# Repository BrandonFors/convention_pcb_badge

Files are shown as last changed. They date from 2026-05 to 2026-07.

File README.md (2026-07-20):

# Convention Badge Project

## The Idea

To create a custom and interactive badge for conventions. The badge would have at least a display and a lipo power supply and some cool designs on the pcb. It would also probably have buttons for interactivity and other fun things.

## Design

ESP32C3 microcontroller. PCB designed in KiCad. Programming done with espressif

### V1

This design features a basic form factor supporting the XIAO esp32c3 devboard along with a 2.9 inch display module. The design was never actually manufactured.

### V2

The V2 board was designed to serve as both a badge and a dev board. It hosts the esp32c3, has support for USB power and flashing, has a battery managment circuit, and various peripherals. The display circuitry still lies on a breakout board which is attached through header pins. It is designed to resemble a satelite.

This design experience was particularly new/challenging because it was the first PCB design I made where I had to consider how parts and integrated circuits interact rather than wiring pin headers together. I also had to consider manufacturing requirements, part availability, and cost.

After manufacturing this board through JLCPCB, I was able to flash the ESP32C3 over USBC and get my display, buttons, and leds working. However, there were a few mistakes within the battery managment circuit that made LiPo power unusable for this version. I was able to fix one to get battery charging working, but a misconfigured mosfet connection made powering the uC with the battery impossible without some reworking which I don't have the tools for. 

Code at this stage is pretty scrappy as the main focus was on PCB design and just getting a prototype working.

Overall, I consider this version great progress and a great step towards improving my PCB design skills. Even though the main complexity of the battery managment circuitry doesn't work, I know what to fix in my next revision. This was my first project where programming wasn't really the main focus and I feel that I have a solid understanding of what to expect the design process to look like in my next KiCad project.

### V3 

Not Started.

This version will ideally look more like a sattelite or whatever form factor represents my interests. It also may switch to a digital display to enable more interactivity than an e-ink offers. 

Things that I had to rework/need to be fixed from V2:
- N-Mosfet for power source switching must align with datasheet
- Bulk capacitor added to display's power and GND. 
- S1 on FS8205A must be connected to ground. 
- Make lanyard hole a little smaller.
- Research general rules on where to put bulk/decoupling capacitors in a design and what type of capacitors are needed in various scenarios. 

## KiCad

All relevant kicad files can be found in `convention_badge_kicad`. We'll probably start by designing a basic board that would just serve as a platform for the esp32-c3 xiao and an e-paper breakoutboard with pin headers. After that, we can scale up complexity and embed the uC on the pcb badge and choose whether or not to design the badge with an FCC connection. 

One reference we are using is Notre Dame's build-a-board workshop pcb design which features a working esp32-c3 breakout board design.

Build-A-Board Credits: https://engineering.nd.edu/news/electrical-engineering-students-create-circuit-boards-in-inaugural-build-a-board-workshop/

# Design Notes

Everything below here is scattered notes from my dev process.

## Display options

### ESP32C3
Datasheet (contains schematics): https://documentation.espressif.com/esp32-c3-wroom-02_datasheet_en.pdf

- could go with xiao module as a backup
- could break out all available gpios to exposed vias to double as a breakout board for future use

### 2.13 inch e-Paper Display Module

 https://www.buydisplay.com/black-2-13-inch-e-paper-122x250-display-module-for-arduino-raspberry-pi

Datasheet: https://www.buydisplay.com/download/manual/ER-EPD0213-2-5076_Datasheet.pdf

UC8251 Controller: https://www.buydisplay.com/download/ic/UC8251.pdf

- is a breakout board and would be good for development on a breadboard. 
- has mounting holes that would be easy to use for the badge
- tutorial exists online for developing an entire display driver for this specific board.

The raw pannel: https://www.buydisplay.com/graphic-2-13-inch-122x250-electronic-paper-display-manufacturers

### 2.9 inch e-Paper Display Module

* probably the best considering size and scalability

https://www.buydisplay.com/black-2-9-inch-e-paper-display-module-for-arduino-raspberry-pi#

Datasheet: https://www.buydisplay.com/download/manual/ER-EPD029-2-5073_Datasheet.pdf

SSD1680 Controller: https://www.buydisplay.com/download/ic/SSD1680.pdf

- development board that is slightly larger and probably better for display purposes
- option for a breakout board and raw board if we decide to integrate pannel regulation into badge

The raw pannel: https://www.buydisplay.com/serial-2-9-inch-e-paper-screen-128x296-for-electronic-shelf-label-lcd

### 2.6 inch e-Paper Display Pannel

https://www.buydisplay.com/2-6-inch-e-ink-152x296-e-paper-display-panel-red-white-black-spi

Datasheet: https://www.buydisplay.com/download/manual/ER-EPD026A1-1_Datasheet.pdf

SSD1675A Controller: https://www.buydisplay.com/download/ic/SSD1675A.pdf

FCC Cable: https://www.buydisplay.com/download/connector/ER-CON24HT-1.pdf

- doesn't have breakout board 
- slightly larger
- requires 24 pin fcc ribbon cable and a connector

## Manufacturing

Most likely JLCPCB

Will likely have to pay for at least partial assembly. 

## Price Estimate

Claude session resulted in price estimate of ~$32 per board including assembly and shipping on an order of 5.

To minimize price, we can design a one sided board (the back) and hand solder buttons and attach the scren on the front. I don't think that prevents solder mask designs on the front. 

## Design Notes

### PCB_BadgeV1

This board will utilize the XIAO ESP32 C3 and an 2.9 inch e-Paper Display Module for functionality. Both will be soldered to the badge using header pins. A 3.7V lipo battery will be soldered to the underside of the xiao module as I don't have a way to solder the pads directly to the badge board. The board will also have some buttons on remaining usable gpio pins. 

This board is largely complete and contains support for a 2.9 inch epaper breakout and and esp32 c3 xiao soldered to the board using male header pins. One pin is wired to a voltage divider for battery power readings. The board also has support for 3 standard 6mm buttons which use internal pull up resistors on the esp32-c3. Footprints are mostly for through hole breadboard components purely because I am not space constrained and wanted to design the board for components that I already had on hand to avoid shipping/assembly costs.

The odds are that this board is never manufactured just because the next one will feature more peripherals as it won't be constrained by the pinout of the xiao. V2 will support the esp32-c3 directly on the pcb, based largely on the Build-A-Board pcb mentioned above.

Note: This board does not have decoupling capacitors between the e paper display and the 3.3V xiao supply.

#### Notable Resources

XIAO Getting Started: https://wiki.seeedstudio.com/XIAO_ESP32C3_Getting_Started/

Display Datasheet: Datasheet: https://www.buydisplay.com/download/manual/ER-EPD029-2-5073_Datasheet.pdf

### PCB_BadgeV2

This board will be 4 layers with support for the esp32-c3 directly on the pcb. Whether or not the board supports the e-paper display directly with no breakout is TBD. I might opt for a hybrid board that supports both the breakout board and the raw screen with solder bridges to enable/disable either set of connections. 

Section 13 of the SSD1680 Datasheet has a diagram of exactly what the 24 pin connector should be wired to.

10k PU with a 1uF capacitor on the EN line creates a RC time constant of 10ms, allowing EN to stay low on to 3.3V stabalizes so the chip boots properly.

I need some way to handle the battery managment of this design. I think I might need a battery charging IC.

Need to make sure that parts are in stock in jlcpcb

https://jlcpcb.com/parts

Going to create a charging/bms circuit using:
- TP4056
- DW10A
- FS8205A

Then I can use TLV75733P for voltage regulation and hook everything to the output 3.3V from there.

Added breakout pins for debugging purposes

Main section is 54 tall and 90 wide -> top and bottom pannels can be 19 tall w/ 3mm gaps between board and pannels

Hex design is 17.5mm tall and 88.1 mm wide

### Code Development

Notable E-Paper Sections:
- 9: Operation Flow 
- 8: Command Description
- 12.1: Timing table and diagram

Using EastRising's example code and the SD1680 documentation, I've got a working program that prints out an example image onto the screen. The display is electronically configured to be used vertically, but horizontal use is easily fixed with some clever frame buffer software. I'm just going to make it cycle through preconfigured bitmaps with the buttons to control the cycle.

Bitmap Img Converter: https://javl.github.io/image2cpp/

LUT Experiment Notes:
Refresh by default is pretty slow at 1.5 sec
- May be able to cut down with custom lut -> tradeoff is quality bc OTP lut does a full cycle on all pixels to fully clear them
Custom lut provided by east rising results in 0.9 sec refresh but leaves a faded img of the previous frame

In the future I can diff two frame buffers to find the changed pixels/sections and then use the xram and yram start/end points to selectively update the screen to avoid some of the anoying refresh.

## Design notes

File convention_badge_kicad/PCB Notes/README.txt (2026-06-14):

So you wanna make a pcb huh? Well you've come to the (probably wrong but) right place ;)

Here's my initial notes after looking at it for like 5 minutes

Your traces are all the same width, which isn't necessarily bad, but I'm worried about the 3.7V trace. Typically power lines have wider traces because they need to be able to supply the required current. Wider trace = more current capacity. It would be worth looking into  the nominal current draw of whatever you are supplying power to, and then using KiCad's trace width calculator in the project menu (very useful things underneath 'calculator tools') to calculate the minimum width of trace you need

The JST you are using for the battery is in the middle of the board. Fair play if that's what you want, but it'll probably be pretty annoying trying to connect to it. Typically all peripheral connectors are placed as close as possible to the edge of the board and facing out so it is a lot easier to access them (except perhaps for pin headers, but even then they tend to be on the outskirts of the board so they don't interfere with trace layout. In general, the layout for your power system is a but overly complex, and with a few small adjustments of component placement, the layout will be simpler and much more user friendly.

I'm unsure what the purpose of the solder jumper to GND for the battery is (I'm too lazy to check the datasheet of what you are messing with). If the purpose is to add an additional resistor to ground to make a voltage divider, I would suggest just via to GND right at the battery, via to GND close to the GND pad of the resistor and solder jumper from the other pad of the resistor to the voltage divider connection. That saves you from the long trace from the solder jumper to the battery, and in general its standard practice to place GND as close as possible to the pad to reduce the current return path (I don't really understand the physics but everything I see says to reduce the length of the return path as much as possible) Since you are working with low frequency I assume, it probably isn't an issue, but better safe then sorry.

You may be able to mess around with the placement and orientation of the Xiao thingie and your pin header connector to reduce via use. It probably isn't a big deal, but I at least try not to use vias whenever possible. But, if it's unavoidable its not a super big deal for your application

It shouldn't be a huge deal, but try to keep the power lines as far away as possible from the I2C lines. Power lines create larger magnetic fields (more current = more magnetic field intensity) and that can potentially corrupt your data as it is transmitted. Since it's only 3.7V and your lines are really short it shouldn't be a major major issue, but I would look into it to see how big of a problem it will be and just give it some space at least

Finally, your traces a just a bit messy. There's no reason not to use straight lines where applicable (For example, the two resistors can very easily be shifted so that there isn't a little hitch in the trace). Also, you have a weird little hanging trace on the connection to the 3rd button that can be cleaned up

Overall there'd definitely some things to touch up, but overall not too shabby! My biggest advice is to just mess around with component placement so that it 1. Makes sense for the user 2. Doesn't interfere with trace paths (especially for through hole components) *This doesn't apply too much to this board, but is good advice in general* 3. Allows for the simplest trace pathway

You have plenty of space on the board to play around with so don't be scared to try different setups!

LMK if you need any more help, I'm happy to give my thoughts whenever you need :)

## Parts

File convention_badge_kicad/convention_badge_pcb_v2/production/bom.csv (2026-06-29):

Designator | Footprint | Quantity | Value | LCSC Part #
C1 | 0603 | 1 | 1uF | C15849
C10, C3, C4 | C_CASE-A-3216-18(mm) | 3 | 10uF | C7171
C11, C2, C5, C9 | 0603 | 4 | 0.1uF | C14663
C6, C8 | 0603 | 2 | 2.2uF | C23630
C7 | C_CASE-B-3528-21(mm) | 1 | 100uF | C122271
D1 | D_0603 | 1 | YEL_LED | C2290
D2, D7 | D_0603 | 2 | RED_LED | C2286
D3 | D_DO-214AC(SMA) | 1 | SS14 | C2480
J1 | USB_C_Receptacle_GCT_USB4105-xx-A_16P_TopMnt_Horizontal | 1 | USBC | C2765186
J3 | JST_PH_S2B-PH-K_1x02_P2.00mm_Horizontal | 1 | 3.7V Battery | C173752
Q1 | SOT-23 | 1 | AO3401A | C20917
R1, R2 | R_0603 | 2 | 5.1k | C23186
R10, R3, R4 | 0805 | 3 | 10k | C17414
R11, R12, R13, R5, R6, R9 | R_0603 | 6 | 1k | C21190
R7 | R_0603 | 1 | 2.2k | C4190
R8 | R_0603 | 1 | 100 | C22775
SW1, SW2, SW6 | SW-SMD_4P-L5.1-W5.1-P3.70-LS6.5-TL-2 | 3 | SW4X2 | C318884
U1 | ESP32-C3-WROOM-02 | 1 | ESP32-C3-WROOM-02 | C2944070
U2 | SOT-23-6 | 1 | FS8205A | C908265
U3 | ESOP-8_L4.9-W3.9-P1.27-LS6.0-BL-EP | 1 | TP4056 | C16581
U4 | SOT-23-6 | 1 | DW01A | C351410
U5 | SOT-23-5 | 1 | TLV75733PDBV | C485517

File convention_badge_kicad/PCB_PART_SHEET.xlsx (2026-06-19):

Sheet: V1Parts
Part Number | Description | Manufacturer | Package | Designator | Count | Unit Price (USD) | Total Price | URL
113991054 | XIAO ESP32 C3 | seeed studio | Breakout | U1 | 1 | $4.99 | $4.99 | https://www.seeedstudio.com/Seeed-XIAO-ESP32C3-p-5431.html
ER-EPD029-2B-5073 | 2.9" E-Paper Display Breakout | East Rising | Breakout | J1 | 1 | $10.55 | $10.55 | https://www.buydisplay.com/black-2-9-inch-e-paper-display-module-for-arduino-raspberry-pi
2275319 | 3.7V Lipo Batt | Jameco | Battery | N/A | 1 | $6.54 | $6.54 | https://www.jameco.com/z/LJ503035-Jameco-ReliaPro-Lithium-Ion-Polymer-Battery-3-7V-500mAh-Rechargeable_2275319.html
 | 6mm standard push button |  | Through Hole | SW1-3 | 3 | $0.00 | $0.00
2314127 | Switch | Jameco | Through Hole | SW4 | 1 | $0.85 | $0.85 | https://www.jameco.com/z/EG218-Jameco-ValuePro-Slide-Switch-SPDT-ON-ON-500mA-50VDC-3-Pin-Breadboard-Friendly_2314127.html
 |  |  |  |  |  |  | $0.00
 |  |  |  |  |  |  | $0.00
 |  |  |  |  |  |  | $0.00
 |  |  |  |  |  |  | $0.00
 |  |  |  |  |  |  | $0.00
 |  |  |  |  |  |  | $0.00
 |  |  |  |  |  |  | $0.00
 |  |  |  |  |  |  | $0.00
 |  |  |  |  |  |  | $0.00
 |  |  |  |  |  |  | $0.00
 |  |  |  |  |  |  | $0.00
 |  |  |  |  |  |  | $0.00
 |  |  |  |  |  | Total Cost: | $22.93

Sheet: V2Parts
Part Number (JLCPCB) | Description | Manufacturer | Package | Designator | Count | Unit Price (USD) | Total Price | URL
 | Esp32C3 | espressif | Surface Mount |  | 1 |  | 0

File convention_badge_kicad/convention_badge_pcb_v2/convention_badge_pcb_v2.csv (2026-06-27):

Reference | Qty | Value | DNP | Footprint | LCSC
C1 | 1 | 1uF |  | Capacitor_SMD:C_0603_1608Metric | C15849
C2,C5,C9,C11 | 4 | 0.1uF |  | Capacitor_SMD:C_0603_1608Metric | C1590
C3,C4,C10 | 3 | 10uF |  | PCM_JLCPCB:C_CASE-A-3216-18(mm) | C7171
C6,C8 | 2 | 2.2uF |  | Capacitor_SMD:C_0603_1608Metric | C1607
C7 | 1 | 100uF |  | PCM_JLCPCB:C_CASE-B-3528-21(mm) | C122271
D1 | 1 | YEL_LED |  | PCM_JLCPCB:D_0603 | C2287
D2,D7 | 2 | RED_LED |  | PCM_JLCPCB:D_0603 | C2286
D3 | 1 | SS14 |  | PCM_JLCPCB:D_DO-214AC(SMA) | C2480
D4,D5 | 2 | LED | DNP | LED_THT:LED_D5.0mm
DISP1 | 1 | EPaper Breakout | DNP | 2_Displays:2.9_e_paper_ER-EPD029-2-5073
J1 | 1 | USBC |  | Connector_USB:USB_C_Receptacle_GCT_USB4105-xx-A_16P_TopMnt_Horizontal | C2765186
J2 | 1 | Conn_01x03_Pin | DNP | Connector_PinHeader_2.54mm:PinHeader_1x03_P2.54mm_Vertical
J3 | 1 | 3.7V Battery | DNP | Connector_JST:JST_PH_S2B-PH-K_1x02_P2.00mm_Horizontal | C173752
J4,J5 | 2 | Conn_01x07_Pin | DNP | Connector_PinHeader_2.54mm:PinHeader_1x07_P2.54mm_Vertical
Q1 | 1 | AO3401A |  | Package_TO_SOT_SMD:SOT-23 | C20917
R1,R2 | 2 | 5.1k |  | PCM_JLCPCB:R_0603 | C23186
R3,R4,R10 | 3 | 10k |  | Resistor_SMD:R_0805_2012Metric | C17414
R5,R6,R9,R11,R12,R13 | 6 | 1k |  | PCM_JLCPCB:R_0603 | C21190
R7 | 1 | 2.2k |  | PCM_JLCPCB:R_0603 | C4190
R8 | 1 | 100 |  | PCM_JLCPCB:R_0603 | C22775
SW1,SW2,SW6 | 3 | SW4X2 |  | PCM_JLCPCB:SW-SMD_4P-L5.1-W5.1-P3.70-LS6.5-TL-2 | C318884
SW3,SW4,SW5 | 3 | SW_Push | DNP | Button_Switch_THT:SW_PUSH_6mm
U1 | 1 | ESP32-C3-WROOM-02 |  | RF_Module:ESP32-C3-WROOM-02 | C2944070
U2 | 1 | FS8205A |  | Package_TO_SOT_SMD:SOT-23-6 | C908265
U3 | 1 | TP4056 |  | PCM_JLCPCB:ESOP-8_L4.9-W3.9-P1.27-LS6.0-BL-EP | C16581
U4 | 1 | DW01A |  | Package_TO_SOT_SMD:SOT-23-6 | C351410
U5 | 1 | TLV75733PDBV |  | Package_TO_SOT_SMD:SOT-23-5 | C485517

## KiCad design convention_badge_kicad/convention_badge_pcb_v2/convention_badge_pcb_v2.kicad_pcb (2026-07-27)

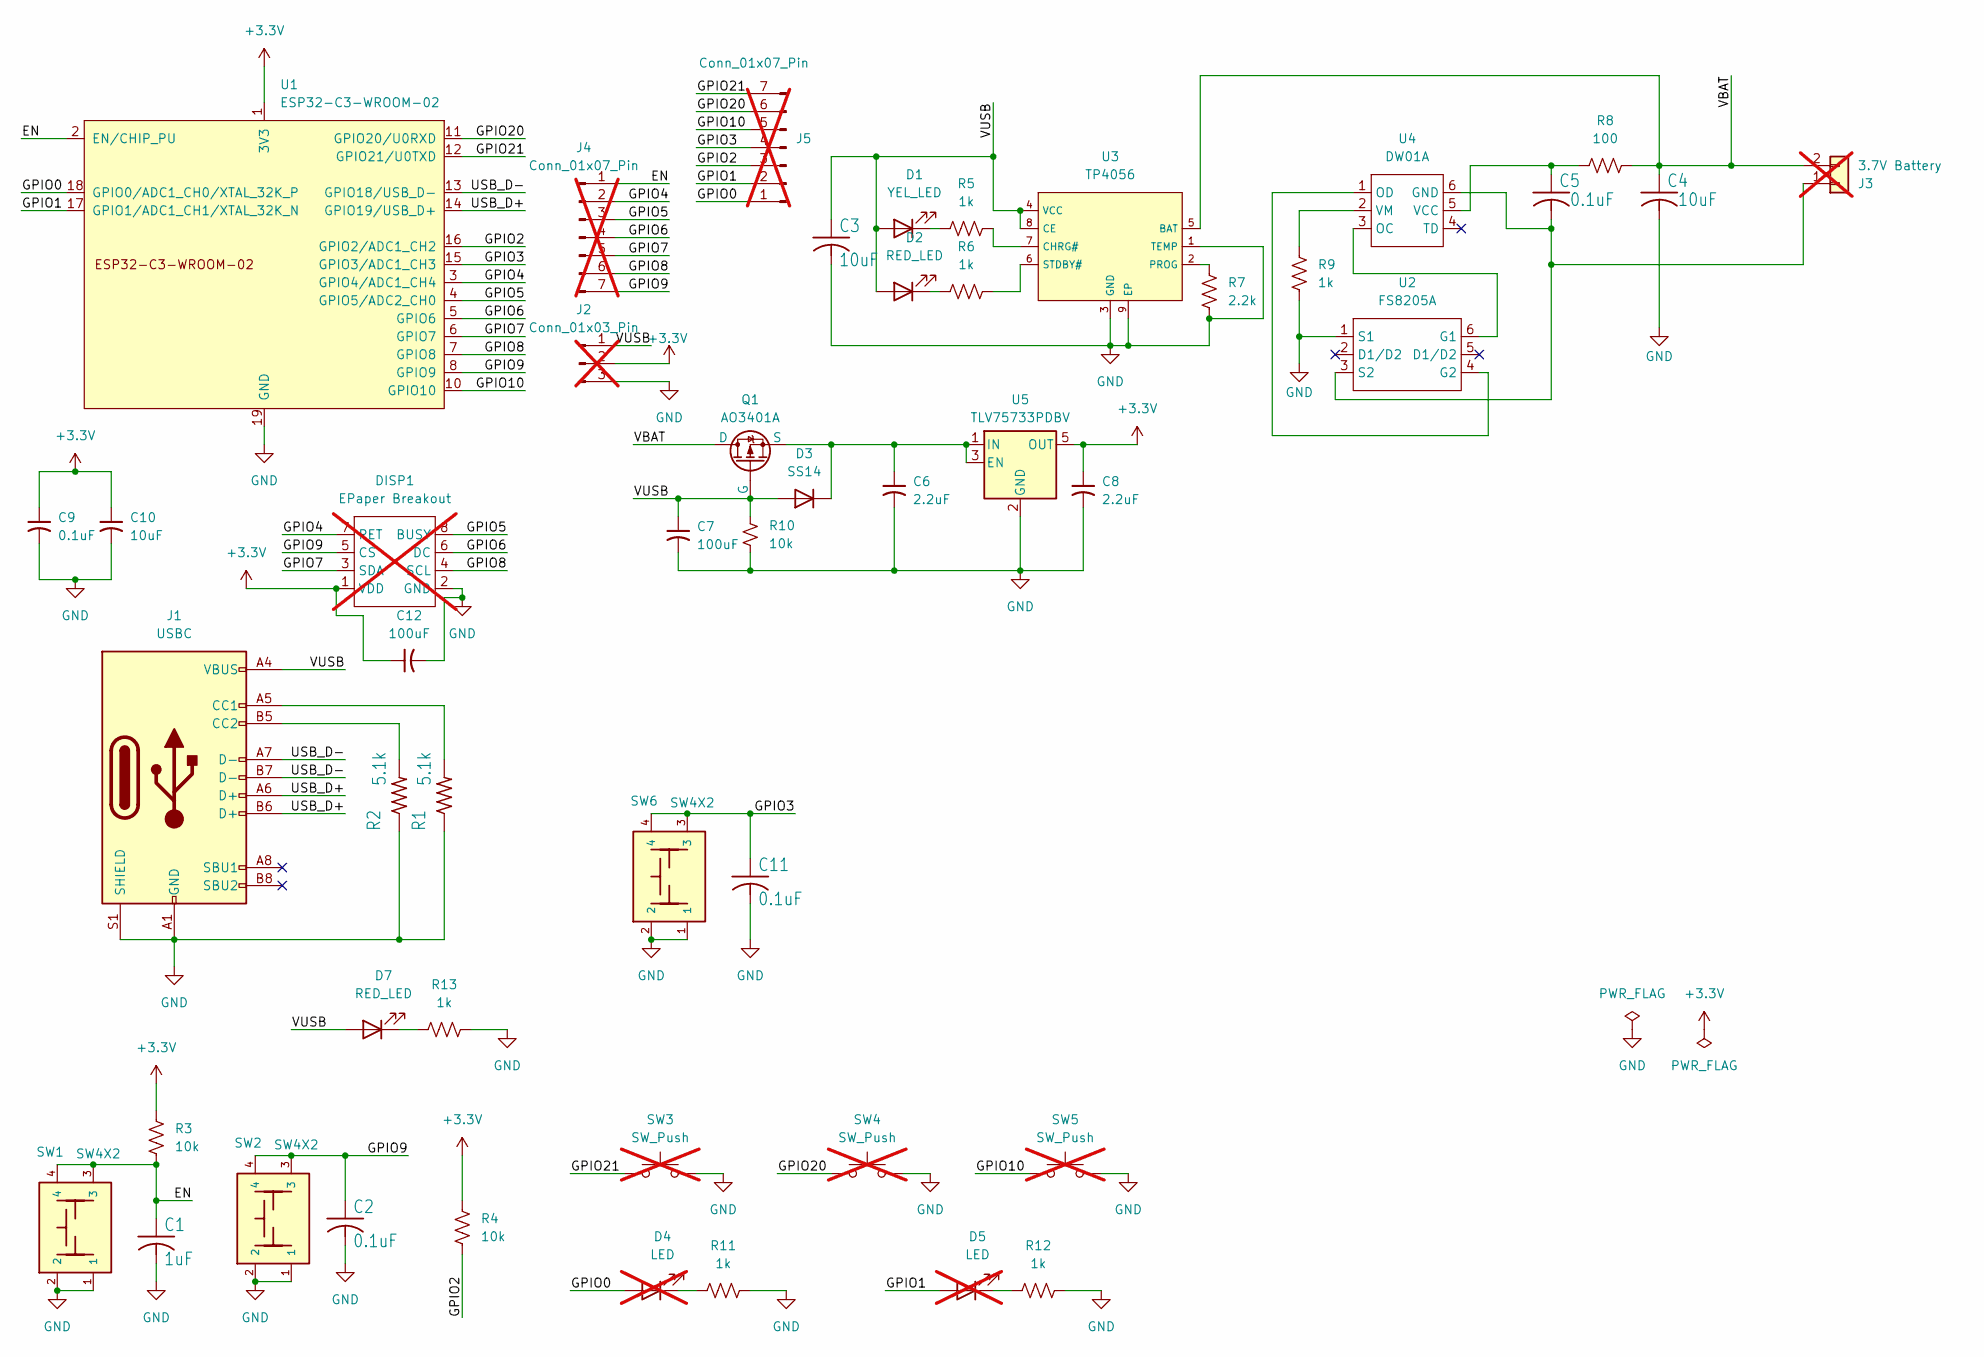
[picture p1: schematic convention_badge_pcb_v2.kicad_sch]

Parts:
C1: 1uF; C_0603_1608Metric; LCSC C15849
C2, C5, C9, C11: 0.1uF; C_0603_1608Metric; LCSC C14663
C3, C4, C10: 10uF; C_CASE-A-3216-18(mm); LCSC C7171
C6, C8: 2.2uF; C_0603_1608Metric; LCSC C23630
C7, C12: 100uF; C_CASE-B-3528-21(mm); LCSC C122271
D1: YEL_LED; D_0603; LCSC C2290
D2, D7: RED_LED; D_0603; LCSC C2286
D3: SS14; D_DO-214AC(SMA); LCSC C2480
D4, D5: LED; LED_D5.0mm; not fitted
DISP1: EPaper Breakout; 2.9_e_paper_ER-EPD029-2-5073; not fitted
J1: USBC; USB_C_Receptacle_GCT_USB4105-xx-A_16P_TopMnt_Horizontal; LCSC C2765186
J2: Conn_01x03_Pin; PinHeader_1x03_P2.54mm_Vertical; LCSC C2337; not fitted
J3: 3.7V Battery; JST_PH_S2B-PH-K_1x02_P2.00mm_Horizontal; LCSC C173752; not fitted
J4, J5: Conn_01x07_Pin; PinHeader_1x07_P2.54mm_Vertical; not fitted
Q1: AO3401A; SOT-23; LCSC C20917
R1, R2: 5.1k; R_0603; LCSC C23186
R3, R4, R10: 10k; R_0805_2012Metric; LCSC C17414
R5, R6, R9, R11, R12, R13: 1k; R_0603; LCSC C21190
R7: 2.2k; R_0603; LCSC C4190
R8: 100; R_0603; LCSC C22775
SW1, SW2, SW6: SW4X2; SW-SMD_4P-L5.1-W5.1-P3.70-LS6.5-TL-2; LCSC C318884
SW3, SW4, SW5: SW_Push; SW_PUSH_6mm; not fitted
U1: ESP32-C3-WROOM-02; LCSC C2944070
U2: FS8205A; SOT-23-6; LCSC C908265
U3: TP4056; ESOP-8_L4.9-W3.9-P1.27-LS6.0-BL-EP; Part TP4056-42-ESOP8; LCSC C16581
U4: DW01A; SOT-23-6; LCSC C351410
U5: TLV75733PDBV; SOT-23-5; LCSC C485517

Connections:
+3.3V: C8.1, C9.1, C10.1, C12.1, DISP1.1 (VDD), J2.2, R3.1, R4.1, U1.1 (3V3), U5.5 (OUT)
/EN: C1.1, J4.1, R3.2, SW1.3, SW1.4, U1.2 (EN/CHIP_PU)
/GPIO0: D4.2 (A), J5.1, U1.18 (GPIO0/ADC1_CH0/XTAL_32K_P)
/GPIO1: D5.2 (A), J5.2, U1.17 (GPIO1/ADC1_CH1/XTAL_32K_N)
/GPIO2: J5.3, R4.2, U1.16 (GPIO2/ADC1_CH2)
/GPIO3: C11.1, J5.4, SW6.3, SW6.4, U1.15 (GPIO3/ADC1_CH3)
/GPIO4: DISP1.7 (RET), J4.2, U1.3 (GPIO4/ADC1_CH4)
/GPIO5: DISP1.8 (BUSY), J4.3, U1.4 (GPIO5/ADC2_CH0)
/GPIO6: DISP1.6 (DC), J4.4, U1.5 (GPIO6)
/GPIO7: DISP1.3 (SDA), J4.5, U1.6 (GPIO7)
/GPIO8: DISP1.4 (SCL), J4.6, U1.7 (GPIO8)
/GPIO9: C2.1, DISP1.5 (CS), J4.7, SW2.3, SW2.4, U1.8 (GPIO9)
/GPIO10: J5.5, SW5.1, U1.10 (GPIO10)
/GPIO20: J5.6, SW4.1, U1.11 (GPIO20/U0RXD)
/GPIO21: J5.7, SW3.1, U1.12 (GPIO21/U0TXD)
/USB_D+: J1.A6 (D+), J1.B6 (D+), U1.14 (GPIO19/USB_D+)
/USB_D-: J1.A7 (D-), J1.B7 (D-), U1.13 (GPIO18/USB_D-)
/VBAT: C4.1, J3.2, Q1.3 (D), R8.2, U3.5 (BAT)
/VUSB: C3.1, C7.1, D1.2 (A), D2.2 (A), D3.2 (A), D7.2 (A), J1.A4 (VBUS), J1.A9 (VBUS), J1.B4 (VBUS), J1.B9 (VBUS), J2.1, Q1.1 (G), R10.1, U3.4 (VCC), U3.8 (CE)
GND: C1.2, C2.2, C3.2, C4.2, C6.2, C7.2, C8.2, C9.2, C10.2, C11.2, C12.2, DISP1.2 (GND), J1.A1 (GND), J1.A12 (GND), J1.B1 (GND), J1.B12 (GND), J1.S1 (SHIELD), J2.3, R1.1, R2.1, R7.1, R9.1, R10.2, R11.2, R12.2, R13.2, SW1.1, SW1.2, SW2.1, SW2.2, SW3.2, SW4.2, SW5.2, SW6.1, SW6.2, U1.9 (GND), U1.19 (GND), U2.1 (S1), U3.1 (TEMP), U3.3 (GND), U3.9 (EP), U5.2 (GND)
unnamed: D1.1 (K), R5.1
unnamed: D2.1 (K), R6.1
unnamed: C6.1, D3.1 (K), Q1.2 (S), U5.1 (IN), U5.3 (EN)
unnamed: D4.1 (K), R11.1
unnamed: D5.1 (K), R12.1
unnamed: D7.1 (K), R13.1
unnamed: J1.A5 (CC1), R1.2
unnamed: J1.B5 (CC2), R2.2
unnamed: C5.2, J3.1, U2.3 (S2), U4.6 (GND)
unnamed: U2.6 (G1), U4.3 (OC)
unnamed: U2.4 (G2), U4.1 (OD)
unnamed: R5.2, U3.7 (CHRG#)
unnamed: R7.2, U3.2 (PROG)
unnamed: R6.2, U3.6 (STDBY#)
unnamed: C5.1, R8.1, U4.5 (VCC)
unnamed: R9.2, U4.2 (VM)

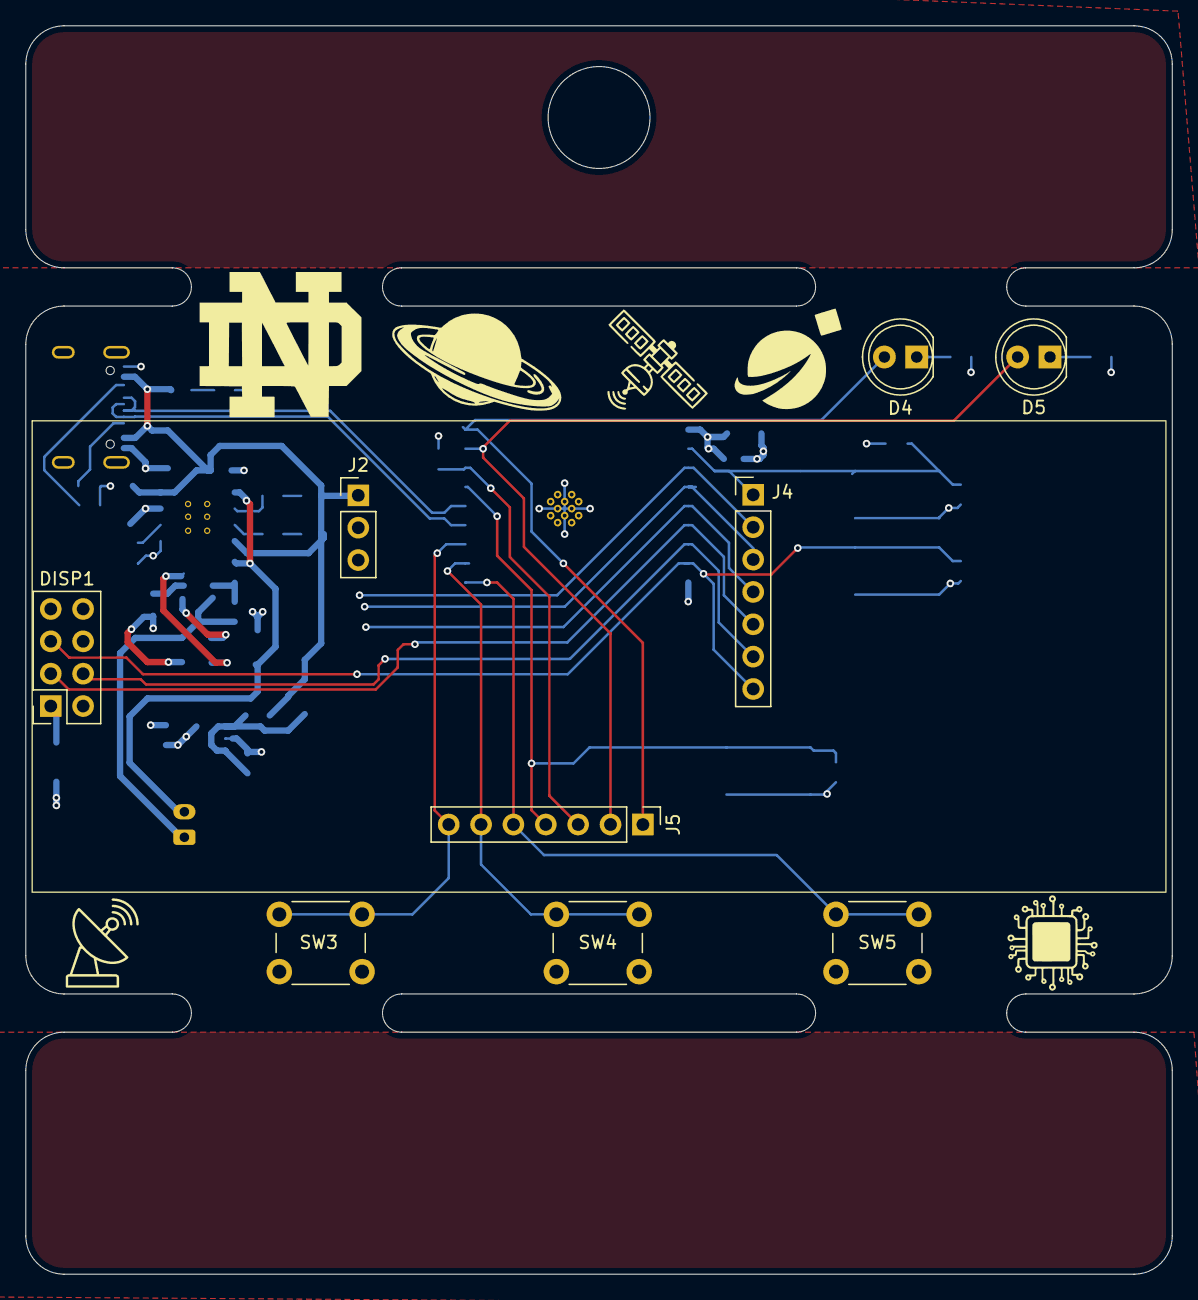
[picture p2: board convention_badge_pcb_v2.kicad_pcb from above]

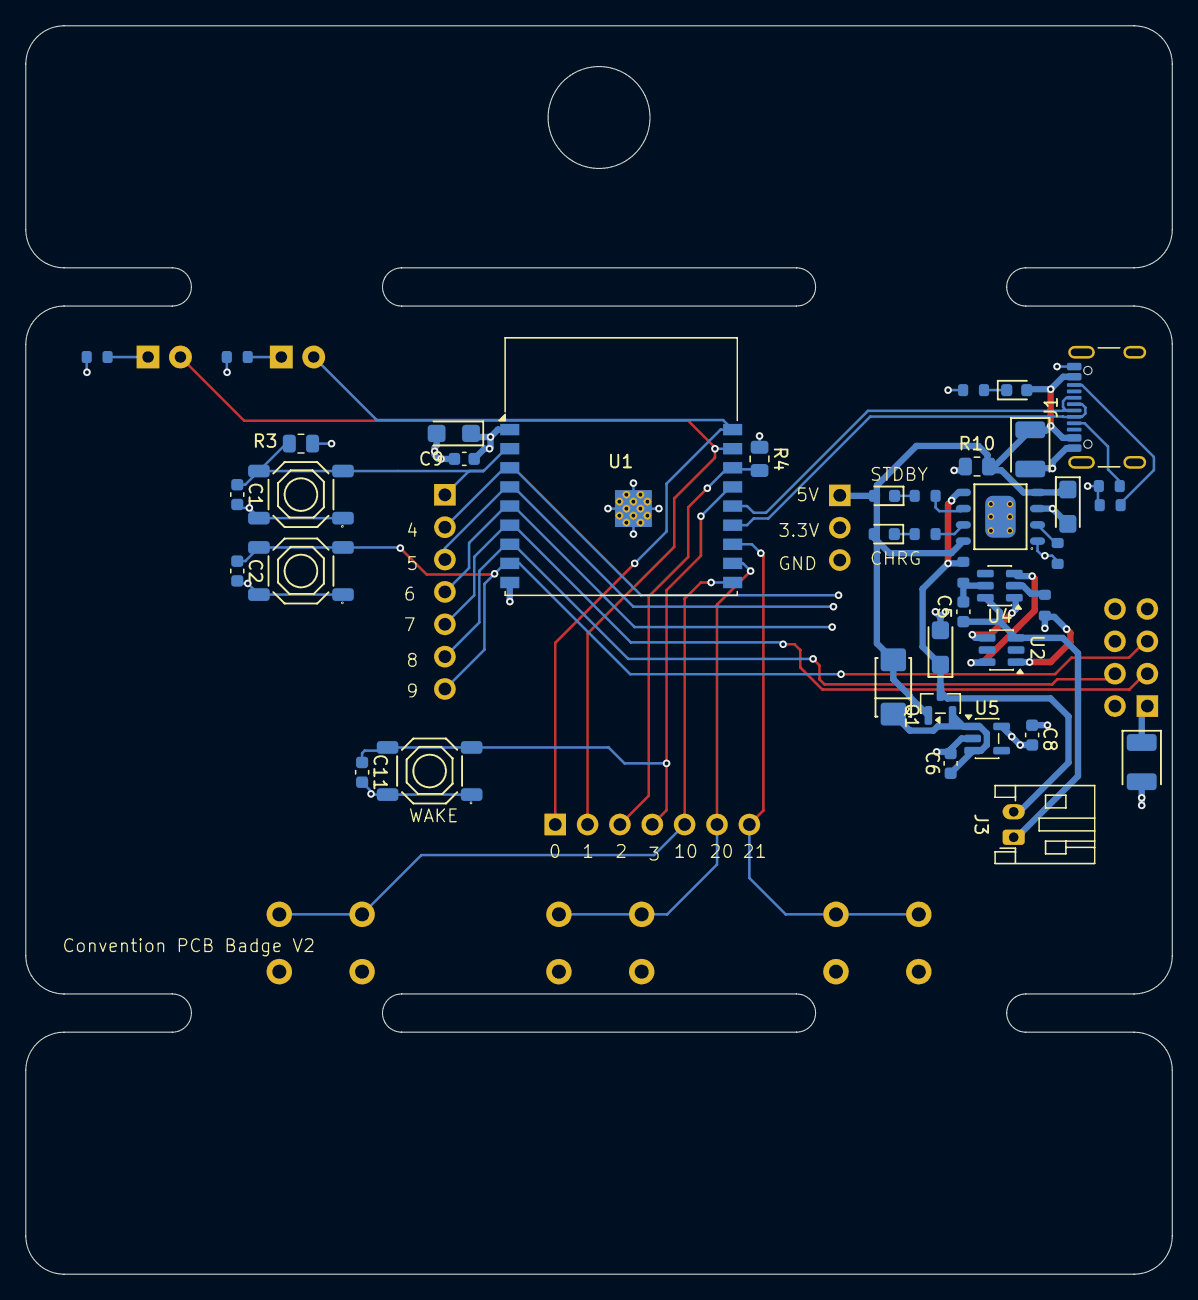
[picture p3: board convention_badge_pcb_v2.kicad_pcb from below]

Board: 4 copper layers, 90.0 x 98.0 mm, 49 parts (40 on the bottom side), 36 nets.

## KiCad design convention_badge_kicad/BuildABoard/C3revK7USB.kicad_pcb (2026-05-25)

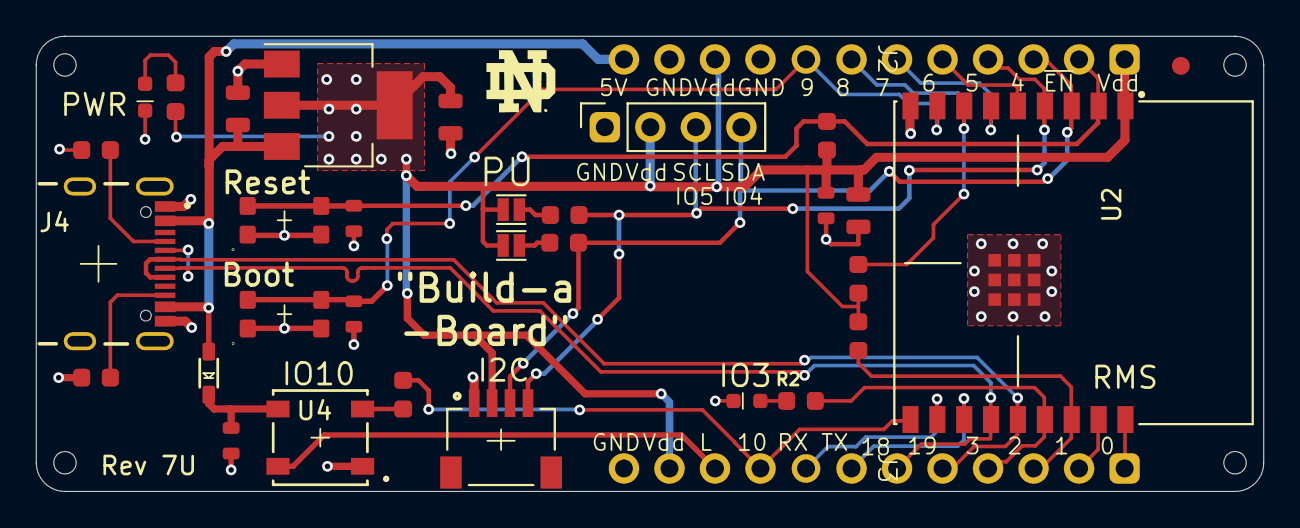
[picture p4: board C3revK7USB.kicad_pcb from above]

Board: 2 copper layers, 68.5 x 25.4 mm, 38 parts (0 on the bottom side), 28 nets.

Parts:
C1, C5: 10uf; STA_RMCF0805_STP
C2: 22uf; STA_RMCF0805_STP
C3, C6: .1uf; C0603
C4, C7: 1uf; C0603
D1: 1N4148; SOD323
FID1: Fiducial; Fiducial_1mm_Mask2mm
H1, H2, H3, H4: MountingHole; MountingHole_Small
J1: I2C; JST04_1MM_RA
J2, J3: Conn_01x12_Pin; Pin12rms
J4: USBC; GCT4105
JP1, JP3: DNP; Jumper_NO_Small
JP2: OLED; 1x4 Socket
LED1: Green; LED_0603
LED2: Blue; LED_0603
Logo1: LOGO; blocknd5x5
R1, R2: 1k; R0603
R3, R4, R5: 10k; R0603
R6, R7: 4.7k; R0603
R14: 470; R0603
R16, R17: 5.1k; R0603
SW1, SW2: SW4X2; PB4X2
U1: AZ1117; SOT223
U2: ESP32-C3; ESP32-C3-WROOM
U4: IN-5X5-LED; LED5x5mm

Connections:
/CC1: J4.A5 (CC1), R17.2
/CC2: J4.B5 (CC2), R16.2
/D+: J3.5, J4.A6 (DP), J4.B6 (DP), U2.14 (IO19)
/D-: J3.6, J4.A7 (DN), J4.B7 (DN), U2.13 (IO18)
/IO0: J3.1, U2.18 (IO0)
/IO1: J3.2, U2.17 (IO1)
/IO2: J3.3, R3.1, U2.16 (IO2)
/IO3: J3.4, R2.2, U2.15 (IO3)
/IO4/SDA: J1.3 (SDA), J2.3, JP2.4 (SDA), R6.1, U2.3 (IO4)
/IO5/SCL: J1.4 (SCL), J2.4, JP2.3 (SCL), R7.1, U2.4 (IO5)
/IO6: J2.5, U2.5 (IO6)
/IO7: J2.6, U2.6 (IO7)
/IO8: J2.7, R4.1, U2.7 (IO8)
/IO9: C3.1, J2.8, SW2.2, SW2.3, U2.8 (IO9)
/IO10: J3.9, R14.1, U2.10 (IO10)
/LED_O: J3.10, U4.2 (DOUT)
/VUSB: C1.1, D1.2, J2.12, J4.A4_B9 (VUSB), J4.B4_A9 (VUSB), U1.3 (INPUT)
/W-RX: J3.8, U2.11 (RXD)
/W-TX: J3.7, U2.12 (TXD)
/~EN: C4.1, J2.2, R5.1, SW1.2, SW1.3, U2.2 (EN)
GND: C1.2, C2.2, C3.2, C4.2, C5.2, C6.2, C7.2, J1.1 (GND), J2.9, J2.11, J3.12, J4.A1_B12 (GND), J4.B1_A12 (GND), J4.S1 (SHELL_GND), J4.S2 (SHELL_GND), J4.S3 (SHELL_GND), J4.S4 (SHELL_GND), JP2.1 (GND), LED1.1 (C), LED2.1 (C), R16.1, R17.1, SW1.1, SW1.4, SW2.1, SW2.4, U1.1 (GND), U2.9 (GND), U2.19 (GND), U2.20 (GND), U2.21 (GND), U2.22 (GND), U2.23 (GND), U2.24 (GND), U2.25 (GND), U2.26 (GND), U2.27 (GND), U4.1 (GND)
unnamed: JP1.1 (A), R6.2
unnamed: JP3.1 (A), R7.2
unnamed: LED1.2 (A), R1.1
unnamed: LED2.2 (A), R2.1
unnamed: C7.1, D1.1, U4.4 (5VDC)
unnamed: R14.2, U4.3 (DIN)
VDD: C2.1, C5.1, C6.1, J1.2 (VCC), J2.1, J2.10, J3.11, JP1.2 (B), JP2.2 (VDD), JP3.2 (B), R1.2, R3.2, R4.2, R5.2, U1.2 (OUTPUT), U2.1 (3V3)

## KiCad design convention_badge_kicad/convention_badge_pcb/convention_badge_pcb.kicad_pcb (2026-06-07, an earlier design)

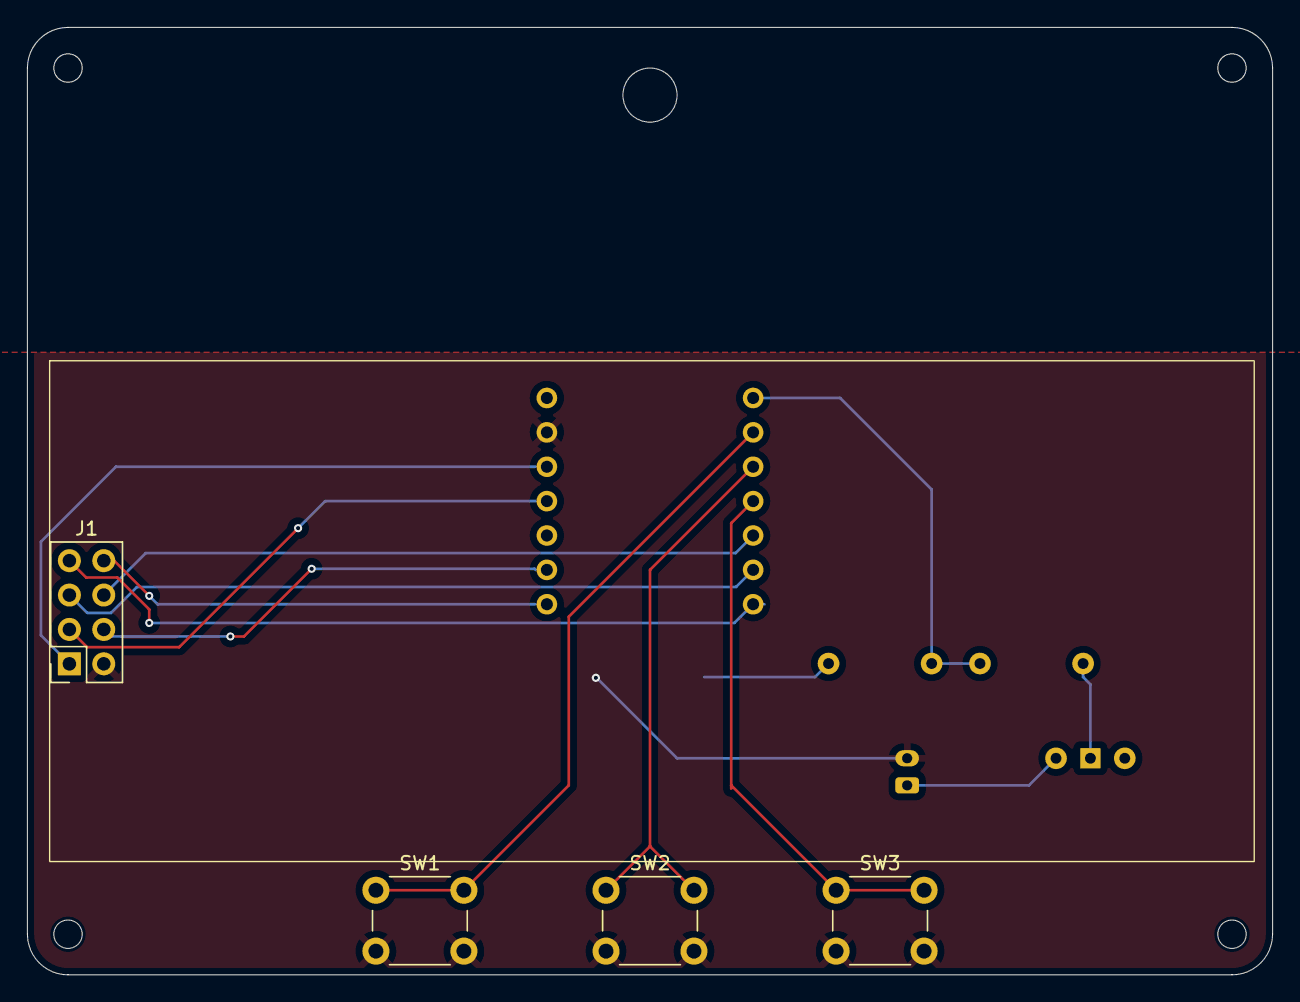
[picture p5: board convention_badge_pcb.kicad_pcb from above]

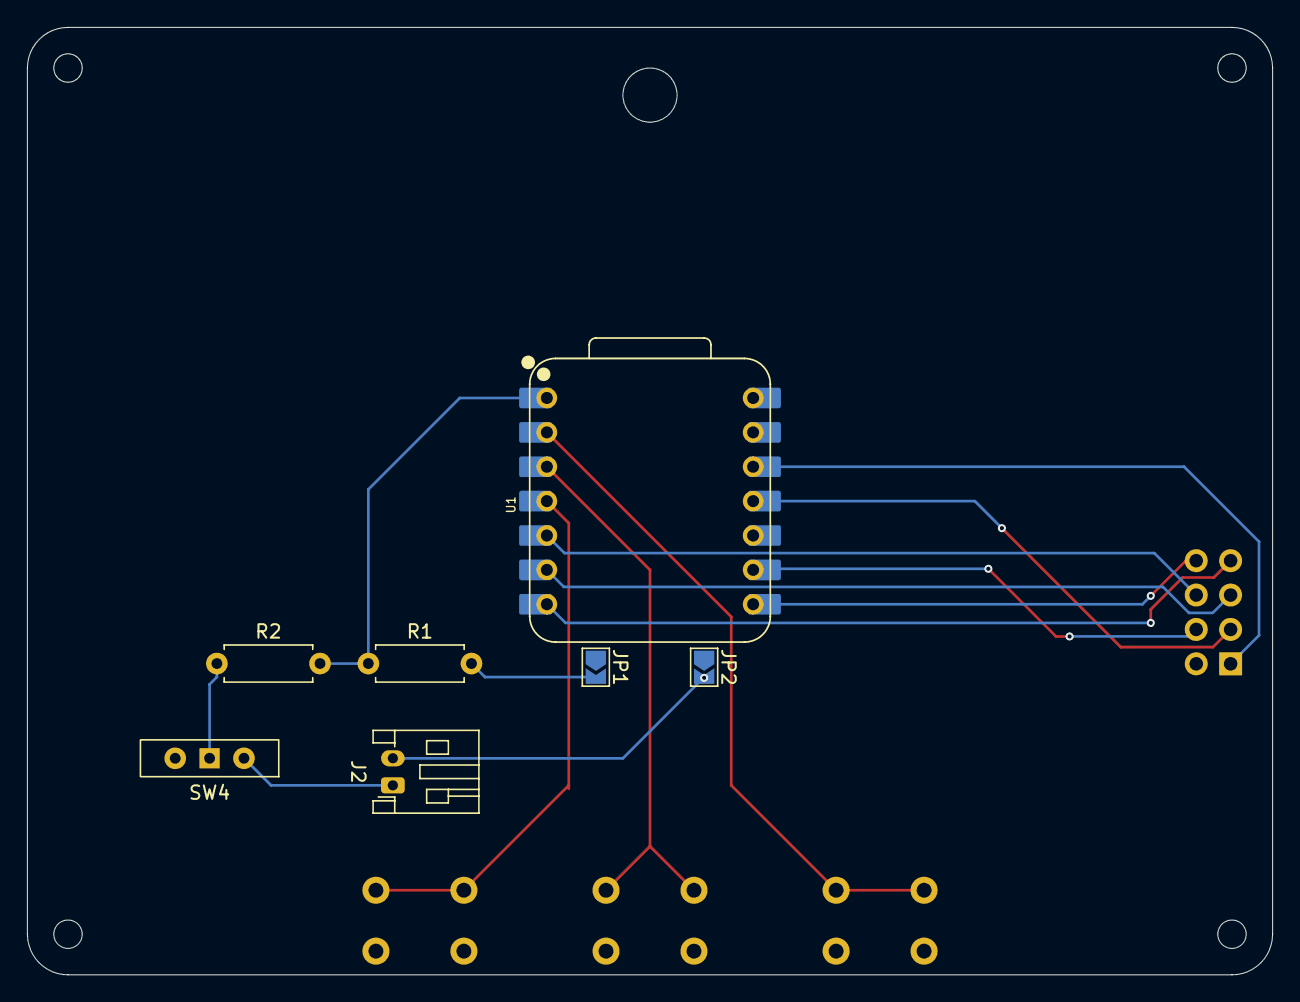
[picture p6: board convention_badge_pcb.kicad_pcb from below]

Board: 2 copper layers, 92.0 x 70.0 mm, 11 parts (7 on the bottom side), 15 nets.

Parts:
J1: E_Paper_Display; 2.9_e_paper_ER-EPD029-2-5073
J2: 3.7V Battery; JST_PH_S2B-PH-K_1x02_P2.00mm_Horizontal
JP1, JP2: SolderJumper_2_Open; SolderJumper-2_P1.3mm_Open_TrianglePad1.0x1.5mm
R1, R2: 220k; R_Axial_DIN0207_L6.3mm_D2.5mm_P7.62mm_Horizontal
SW1, SW2, SW3: SW_Push; SW_PUSH_6mm
SW4: SW_SPST; SW_Slide-03_Wuerth-WS-SLTV_10x2.5x6.4_P2.54mm
U1: XIAO-ESP32-C3-DIP

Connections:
+3.7V: J2.1, SW4.2 (B)
/ADC: R1.1, R2.2, U1.1 (GPIO2_A0_D0)
/BUSY: J1.8, U1.8 (GPIO20_D7_RX)
/BUT_1: SW1.1, U1.2 (GPIO3_A1_D1)
/BUT_2: SW2.1, U1.3 (GPIO4_A2_D2)
/BUT_3: SW3.1, U1.4 (GPIO5_A3_D3)
/CS: J1.5, U1.6 (GPIO7_D5_SCL)
/DC: J1.6, U1.5 (GPIO6_D4_SDA)
/RET: J1.7, U1.7 (GPIO21_D6_TX)
/SCL: J1.4, U1.9 (GPIO8_D8_SCK)
/SDA: J1.3, U1.11 (GPIO10_D10_MOSI)
/VDD: J1.1, U1.12 (3V3)
GND: J1.2, J2.2, JP2.2 (B), SW1.2, SW2.2, SW3.2, U1.13 (GND)
unnamed: JP1.2 (B), R1.2
unnamed: R2.1, SW4.1 (A)

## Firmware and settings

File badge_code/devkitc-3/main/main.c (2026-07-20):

#include <stdio.h>

//espidf drivers
#include "esp_err.h"
#include "esp_log.h"
#include "driver/gpio.h"
#include "esp_timer.h"
#include "driver/gptimer.h"

//Custom
#include "board.h"
#include "hal.h"
#include "buttons.h"
#include "epaper.h"
#include "imgs.h"



#define NUM_BITMAPS 4
#define BETWEEN_SLIDES_MS 15000
#define BETWEEN_BLINKS_MS 1000

static const char *TAG = "MAIN";

static const unsigned char *bitmap_arr[] = {irishsat_bitmap, epd_bitmap_Nametag, epd_bitmap_website, epd_bitmap_opensauce};
volatile uint8_t bitmap_idx = 0;
volatile uint8_t button_flag = 0;
static uint32_t curr_time = 0;
volatile uint32_t last_time = 0;
static uint32_t last_led_time = 0;
static uint8_t led_state = HAL_GPIO_LOW;


void slide_hold(){
    last_time = hal_get_time_ms();
}

void slide_forward(){
    button_flag = 1;
    bitmap_idx++;
    bitmap_idx %= NUM_BITMAPS;
}

void slide_backward(){
    button_flag = 1;
    if(bitmap_idx == 0){
        bitmap_idx = NUM_BITMAPS - 1;
        return;
    }
    bitmap_idx--;
}


void app_main(void)
{
    hal_init();
    buttons_init();
    epaper_init();
    hal_gpio_set(RED_LED_PIN, HAL_GPIO_HIGH);


    while(1){
        curr_time = hal_get_time_ms();
        if(curr_time > last_led_time + BETWEEN_BLINKS_MS){
            led_state = !led_state;
            hal_gpio_set(YEL_LED_PIN, led_state);
            last_led_time = curr_time;
        }
        if(button_flag){
            epaper_write_bitmap(bitmap_arr[bitmap_idx]);
            epaper_push_frame();
            last_time = curr_time;
            button_flag = 0;
        }
        if (curr_time > last_time + BETWEEN_SLIDES_MS){
            ESP_LOGI(TAG, "Writing and Pushing Bitmap");
            epaper_write_bitmap(bitmap_arr[bitmap_idx++]);
            bitmap_idx %= NUM_BITMAPS;
            epaper_push_frame();
            last_time = curr_time;
        }



        ESP_LOGI(TAG, "Spinning");
        hal_delay_ms(100);
    };
}

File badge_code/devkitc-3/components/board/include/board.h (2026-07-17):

#ifndef BOARD_H
#define BOARD_H

#include <stdint.h>


// Button Pins
#define BUT_1_PIN 21
#define BUT_2_PIN 20
#define BUT_3_PIN 10

// E-Paper pins 
#define MOSI_PIN 7 // SPI
#define SCLK_PIN 8 // SPI
#define CS_PIN   9 // GPIO OUT
#define DC_PIN   6 // GPIO OUT
#define RET_PIN  4 // GPIO OUT // Hardware Reset
#define BUSY_PIN 5 // GPIO IN

//LEDS
#define RED_LED_PIN 0
#define YEL_LED_PIN 1



#endif

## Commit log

2026-05-25 initial kicad commit
    [convention_badge_pcb.kicad_pcb, convention_badge_pcb.kicad_sch]
2026-05-25 updated readme and added kicad board reference
    [C3revK7USB.kicad_pcb, C3revK7USB.kicad_sch, convention_badge_pcb.kicad_sch]
2026-05-31 updated board options, prob going with 2.9 incher
2026-06-01 v1 schematic and parts list
    [PCB_PART_SHEET.xlsx, convention_badge_pcb.kicad_pcb, convention_badge_pcb.kicad_sch]
2026-06-04 created footprint for display and made a (very) rough layout of the board
    [convention_badge_pcb.kicad_pcb, convention_badge_pcb.kicad_sch]
2026-06-06 finished v1 layout, will serve as backup for if v2 is unfeasable
    [convention_badge_pcb.kicad_pcb, convention_badge_pcb.kicad_sch]
2026-06-07 modified the board and generated gerbers
    [convention_badge_pcb-B_Cu.gbr, convention_badge_pcb-B_Mask.gbr, convention_badge_pcb-B_Silkscreen.gbr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]
2026-06-10 Added Notes on PCB layout
2026-06-12 built a little more hal and fixed gpio conflict
    [board.h, buttons.c, epaper.c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]
2026-06-14 Added notes for PCB iteration 2
2026-06-19 v2 pcb design progressing
    [PCB_PART_SHEET.xlsx, convention_badge_pcb_v2.kicad_pcb, convention_badge_pcb_v2.kicad_sch]
2026-06-21 schematic minus e paper integration complete
    [convention_badge_pcb_v2.kicad_pcb, convention_badge_pcb_v2.kicad_sch]
2026-06-22 layout is almost complete, kind of a rats nest
    [convention_badge_pcb_v2.kicad_pcb, convention_badge_pcb_v2.kicad_sch]
2026-06-23 cleaned up layout and seperated breakout headers.
    [convention_badge_pcb_v2.kicad_pcb, convention_badge_pcb_v2.kicad_sch]
2026-06-25 made board outline
    [convention_badge_pcb_v2.kicad_pcb, convention_badge_pcb_v2.kicad_sch]
2026-06-26 updated with part numbers and modified board to account for avail parts
    [convention_badge_pcb_v2.csv, convention_badge_pcb_v2.kicad_pcb, convention_badge_pcb_v2.kicad_sch]
2026-06-27 added solar pannel design, almost ready to order
    [bom.csv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]
2026-06-29 submitted to jlcpcb
    [bom.csv, convention_badge_pcb_v2.kicad_pcb, convention_badge_pcb_v2.kicad_sch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]
2026-07-03 added button slide cycling and basic leds
2026-07-17 add readme content, modify pins in code for C3
    [convention_badge_pcb_v2.kicad_pcb, convention_badge_pcb_v2.kicad_sch]
2026-07-20 final notes from testing/use at opensauce, small updates to code to mitigate issues
    [main.c]
2026-07-27 made reworked changes in schematic and layout
    [convention_badge_pcb_v2.kicad_pcb, convention_badge_pcb_v2.kicad_sch]
